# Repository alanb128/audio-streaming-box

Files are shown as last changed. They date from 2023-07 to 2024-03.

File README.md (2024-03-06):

# network-streamer
Create an audiophile streaming music device with [moOde audio](https://moodeaudio.org/), controls and an LCD

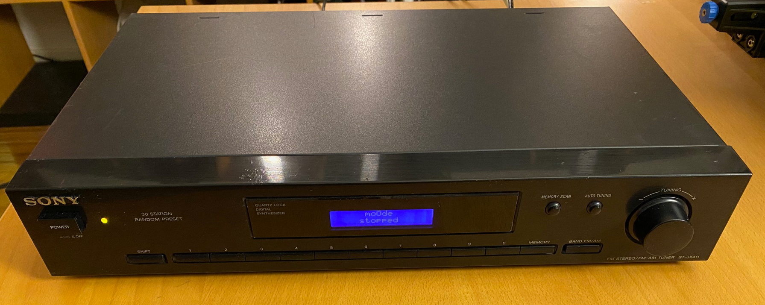
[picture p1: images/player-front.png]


## About
This project started as a means for adding a network audio streaming device to my stereo system. These devices are typically [awesome but expensive](https://www.crutchfield.com/shopsearch/network_streamer.html?&pg=2) so I decided to build one using a Raspberry Pi, an old analog AM/FM tuner's case, and the open-source moOde software. Front panel buttons can be used to select playlists, start/stop music and move to the previous and next track. When integrated into an old stereo component, it fits nicely into a stereo system. I used an old Sony ST-JX411/412/421 series of tuners from the 1990s that are a nice size and have rotary tuning knob.

See the project's video [here](https://youtu.be/9q6N7AinWJA?si=kqSZgW_-xdN4nL4z)!

I hope to add more details and instructions in the future, but the below should get ambitious makers started!

This is an advanced project that requires soldering, tinkering, and some prior experience working with the Raspberry Pi (Python and Docker experience is helpful but not required). This document outlines the basics to get started and create a minumum build. However, if you get stuck or find an issue, feel free to add an issue to this repo!

## Hardware required

- A Raspberry Pi 4-based SBC (2, 4, or 8 GB of RAM) or a CM-4
- Pi accessories such as a MicroSD card and power supply
- An audio DAC HAT for the Pi such as [this](https://www.raspberrypi.com/products/dac-pro/) or [this](https://www.raspberrypi.com/products/dac-plus/) (I used a [digital output HAT](https://www.hifiberry.com/shop/boards/hifiberry-digi2-pro/) with an outboard DAC)
- An LCD alphanumeric display like [this one](https://www.adafruit.com/product/181)
- [i2c / SPI character LCD backpack](https://www.adafruit.com/product/292) for connecting the LCD display to the Pi
- To control the device with switches, you'll need one or more momentary SPST switches, wired into a matrix (see below)

## Setup

### Hardware

- Connect the LCD display to the backpack, and the backpack to the Pi using SPI. ([instructions](https://learn.adafruit.com/i2c-spi-lcd-backpack/python-circuitpython))
- If you have the room, the backpack can be soldered right onto the LCD.
- Connect the DAC HAT to the Pi.
- Wire up your switches in a [key matrix pattern](https://pcbheaven.com/wikipages/How_Key_Matrices_Works/) (see the use of diodes in the link to improve performance)
- Wire the rows and columns of the key matrix to the Pi's GPIO pins (which may be on the DAC HAT if using one of those)
- See the [pad4pi](https://pypi.org/project/pad4pi/) library for more information about the key matrix.
- If you want a "power on" button, add a momentary pushbutton that sends GPIO 3 to ground.
  
### Software

- Download a Moode Audio image for the Pi 4, flash it to a MicroSD card and insert it into the Pi.
- Power up the Pi and make sure Moode works and you get audio out (LCD and buttons will not initially be functional)
- If using LCD, use `raspi-config` to turn on SPI for the screen.
- In the moode UI, under "Local Services" in the "System" menu, turn on "Metadata file" and "LCD updater".
- SSH into your Moode Pi (usually `ssh pi@moode.local` with password `moodeaudio`)
- Install Docker on the pi: https://raspberrytips.com/docker-on-raspberry-pi/ - make sure it starts automatically
- Clone this repo to `/usr/src/app` on device. (You can delete the "alternate" folder.)
- Adjust [the code](https://github.com/alanb128/moode-box/blob/main/controller/flask-api.py#L83) in flask-api on the device to correspond to the GPIO pins you used for your key matrix rows and columns 
- Update `/var/local/www/commandw/lcd_updater.py` and `restart.sh` with the included modified files.
- Issue `docker compose up -d` to start the container. It should always load on its own going forward.

If you make a change to any of the files on the device after this process, issue `docker compose down` then `docker compose build` then `docker compose up`.

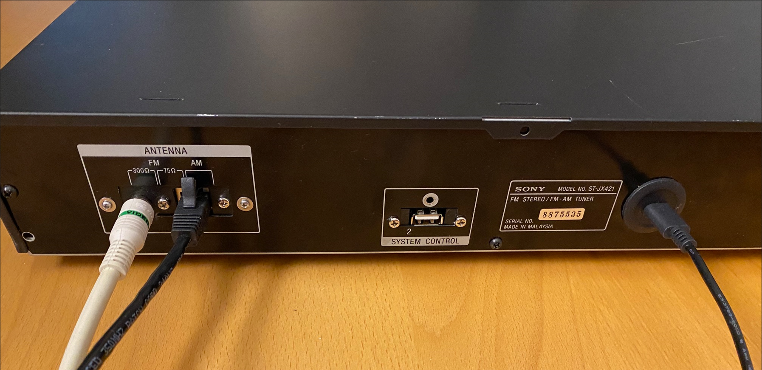
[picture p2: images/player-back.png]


## Reference files

These may be helpful for further programming in the future:

FYI: output of `cat  /var/local/www/currentsong.txt` for both playing a file then playing a stream:

```
file=NAS/Flacs/The Temptations/Vintage Gold/04 - Since I Lost My Baby.flac
artist=The Temptations
album=Vintage Gold
title=Since I Lost My Baby
coverurl=/coverart.php/NAS%2FFlacs%2FThe%20Temptations%2FVintage%20Gold%2F04%20-%20Since%20I%20Lost%20My%20Baby.flac
track=4
date=
composer=
encoded=File does not exist
bitrate=0 bps
outrate=0 bps
volume=100
mute=0
state=stop
```

```
/var/local/www/commandw/lcd_updater.py
/var/local/www/currentsong.txt
pi@moode-dev:~/moodisp $ cat  /var/local/www/currentsong.txt
file=https://ice.cr1.streamzilla.xlcdn.com:8000/sz=RCOLiveWebradio=mp3-192
artist=Radio station
album=RCO Live
title=Robert Schumann: Symphony No. 2 in C major, Op. 61 - RCO Amsterdam - John Eliot Gardiner (7.3.2010)
coverurl=imagesw%2Fradio-logos%2FRCO%20Live.jpg
track=
date=
composer=
encoded=VBR
bitrate=192 kbps
outrate=16 bit, 44.1 kHz, Stereo, 1.411 Mbps
volume=60
mute=0
state=play
```

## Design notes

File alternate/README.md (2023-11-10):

## Alternate

This was the initial setup, using four pushbuttons and an [1.27" OLED screen](https://www.adafruit.com/product/1673).

Using the [Split Body Case DIY 4.72 x 3.82 x 1.57 inch enclosure](https://www.amazon.com/gp/product/B010DHQPVW) and replacing the front and back panel with the 3d printed STL files in the "alternate" folder.

A "power on" momentary pushbutton sends GPIO 3 to ground. The display uses a [3.3v L4931 voltage regulator](https://www.adafruit.com/product/2166) and a 10uf 50v capacitor to provide additional 3v power to the LCD since the HiFiberry Digi2-Pro has 3V current restrictions.

To set this up, use raspi-config to turn on SPI for the screen. Then:

```
sudo pip3 install adafruit-circuitpython-rgb-display
sudo apt-get install fonts-dejavu
sudo apt-get install python3-pil #(Version: 8.1.2 already installed)
```

Update `/var/local/www/commandw/lcd_updater.py` with the code in this repo's alternate folder.

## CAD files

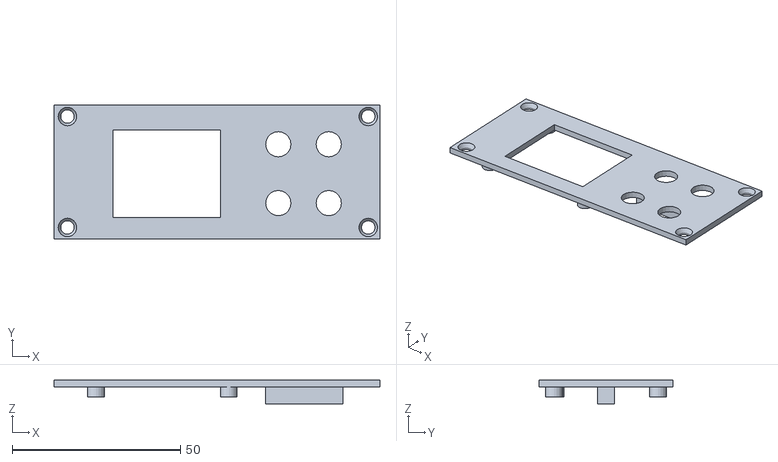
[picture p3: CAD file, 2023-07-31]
alternate/mplayer-f-2e.stl
97.0 x 40.0 x 7.00

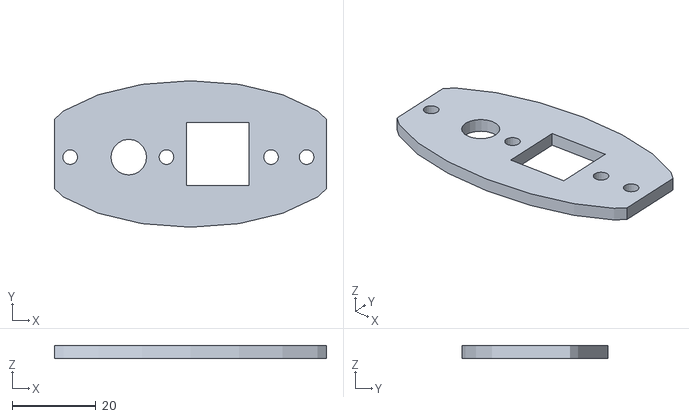
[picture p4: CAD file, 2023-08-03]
st-jx421-eth2b.stl
65.0 x 35.0 x 3.00

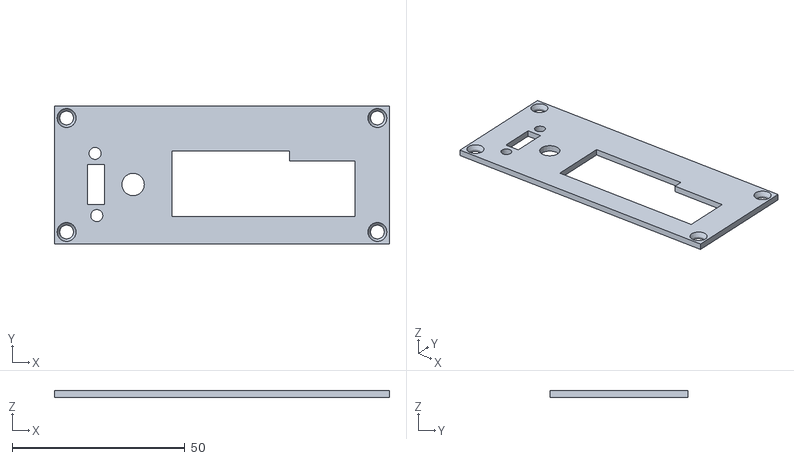
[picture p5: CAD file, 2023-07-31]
alternate/mplayer-r-2b.stl
97.0 x 40.0 x 2.00

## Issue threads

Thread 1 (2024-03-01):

Code related to two colors LED and power button.

net4u, 2024-03-01:
Hello! Can I ask you to help me extract from your source code, only what is strictly related to the power button and the two LEDs (red and green).

alanb128, 2024-03-01:
Hi @net4u - For power on, the momentary switch just needs to connect pin 3 of the PI to ground momentarily. The red and green LEDs are connected to GPIO pins (with resistors) as outputs. In the [power on sequence](https://github.com/alanb128/audio-streaming-box/blob/9c3bc8f823c2baca6be2a2adfcf1c77c53a1da1b/controller/flask-api.py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), the red LED is tuned off and the green is turned on. During [shutdown](https://github.com/alanb128/audio-streaming-box/blob/9c3bc8f823c2baca6be2a2adfcf1c77c53a1da1b/controller/flask-api.py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), the opposite occurs. Let me know if you need more details!

net4u, 2024-03-02:
Hi. I will try tomorrow and then come with feedback. I have to search for an extra LED in my "archived electronics boxes". Thnx a lot.

net4u, 2024-03-04:
Beyond "import RPI.GPIO" I also need to import the other libraries?

net4u, 2024-03-04:
Beyond import RPI.GPIO I need also to import the other libraries?

alanb128, 2024-03-06:
You only need the other libraries if you are doing more than setting the values for the GPIO pins. In other words, if you're just turning on and off the LEDs, that should be the only library you'll need. If you do require another library, an error message should alert you as to which one is missing.

Closed 2025-04-28.

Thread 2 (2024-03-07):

LCD / LCD Backpack wiring

stevemesser, 2024-03-07:
I am trying to make your project. I found a FM tuner exactly like yours.

1. Do you happen to have more detailed wiring information about
    a. LCD and Back pack
    b. How you wired up the tuning knob
    c. the breakout board
2. How did you power the existing front panel?

I am handy with electronics but not as handy as you. Any extra guidance you could provide would be appreciated.

alanb128, 2024-03-07:
> LCD and Back pack

Here's the guide I used for the LCD and backpack: https://learn.adafruit.com/i2c-spi-lcd-backpack

> How you wired up the tuning knob

On my Sony tuners, the tuning knob was included in the row and column matrix, so no additional wiring was required - check the schematic for your exact tuner model. (Even models that look the same can have different model numbers)

> the breakout board

The breakout board was just a way to connect the ribbon cable leads I soldered onto the tuning board to the male GPIO pins on the Pi. It can be done many ways. I used a board like this: https://www.adafruit.com/product/1608 along with a strip of male headers and female-to-female jumpers.

> How did you power the existing front panel

It is actually passive when just using the front panel switches, so no power is needed!

Good luck and keep us posted!

stevemesser, 2024-03-11:
Sony FM control panel button matrix

1. I have removed the current display
2. I have desoldered the chip that was under the display
3. Looking at the schematic I see the matrix you have mentioned in your video.
   What I see is it appears to me that
   Pins 15, 16, 24, 25 seem to be the vertical lines of the matrix
   Pins 30, 31, 33, 34, 35 seem to be the hortizontal lines of the matrix
   Not sure about pins 32 and 33.

I thought that if I connected my multimeter in continuity mode to pins 16 and 30 then pressing the Band button would get a beep. However, it did not.

What I am missing?

alanb128, 2024-03-12:
My schematic is for the "ST_JX412/JX521" so that's what I'm going by. Your numbering sounds correct, but pins 28, 29, and 33 are also rows. Pin 32 is ground - make sure you do not connect the board ground to ground on the Pi or it won't work. I did not try continuity testing on my board so I don't know if you should get a beep or not - I'm not sure how the diodes would affect that.

Also make sure you update the rows and columns in the code to correspond to the GPIO pins you use.

alanb128, 2024-03-13:
The "11 wires instead of 17" is just purely going off the schematic. In my build the four "key input" pins are the columns and the five active "key output" pins are the rows. (Two key output pins don't connect to any switches.)

stevemesser, 2024-03-13:
I have the same device and schematic as you do.
So I am trying to figure out which two wires I don't need

Pin 15 Key Input
Pin 16 Key Input
Pin 24 Key Input
Pin 25 Key Input

Pin 28 Key Output
Pin 29 Key Output
Pin 30 Key Output
Pin 31 Key Output
Pin 33 Key Output
Pin 34 Key Output
Pin 35 Key Output

My guess would be I don't need Pins 28 and 29.

Could you please verify that for me?

alanb128, 2024-03-14:
Correct, I don't think you need pin 28 and 29.

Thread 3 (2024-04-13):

Looking for some troubleshooting help

stevemesser, 2024-04-13:
I have the project completely built.  I tested button presses in a test script so that part is known to work.
My configuration is the same as yours.

I have verified the following
1. In Moode I have enabled LCD Updater
2. In raspi-config I have enables SPI
3. I have verified that currentsong.txt is being populated
4. . I have verified that the docker image is running via docker ps

The issue is that the LCD nor key presses are working.
Not sure what I missed. Not even the momentary push button to GPIO 3 works.

I haven't been able to figure out where the docker container would log errors.

Any thoughts for troubleshooting?

Thanks

alanb128, 2024-04-14:
Looks like the actual Python script may be commented out:
https://github.com/alanb128/audio-streaming-box/blob/e4b1963791e3b94d0bdc0316399793957368005a/controller/Dockerfile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
I must have been troubleshooting at some point and left that in. Comment out the "sleep" line and uncomment the line above, then try again.

stevemesser, 2024-04-14:
Thanks I saw that but wasn't sure. Turns out I had my latch connected to the wrong gpio pin.

alanb128, 2024-04-17:
Is your unit fully working now @stevemesser ?

stevemesser, 2024-04-17:
Sorry,  I got side tracked with a work project.  I hope to work on it again in the next day or so.

stevemesser, 2024-04-17:
The contract pot on the backpack is extremely fickle. I ordered another one

stevemesser, 2024-04-19:
@alanb128  I figured out all my LCD issues. I mentioned above I had tested keypresses. I did however without pad4pi. I figured out how to create a virtual environment in Thonny and was finally able to install pad4pi and write a test script. However, I am getting the following runtime error. Failed to add edge detection. Did I miss some configuration somewhere?

stevemesser, 2024-04-20:
Running the docker log <container id> command the logs are saying that flask import is failing with No module named flask.

Any ideas?

alanb128, 2024-04-20:
Looks like Flask was not being installed. I updated the Dockerfile, so try pulling it again and rebuilding.

stevemesser, 2024-04-20:
Closer, now import request fails.

No module named requests

alanb128, 2024-04-20:
Ok, added that in so you can try again.

(Sometimes I install these modules manually during development and forget to update the repo or push the changes!)

stevemesser, 2024-04-20:
No worries. thanks for helping.
=> ERROR [controller 3/4] RUN     pip3 install flask request adafruit-circuitpython-charlcd pad4pi adafruit-circuitpython-seesaw

.059 Collecting flask
3.245   Downloading flask-3.0.3-py3-none-any.whl (101 kB)
3.318      ━━━━━━━━━━━━━━━━━━━━━━━━━━━━━━━━━━━━━━━ 101.7/101.7 kB 1.6 MB/s eta 0:00:00
3.415 ERROR: Could not find a version that satisfies the requirement request (from versions: none)
3.417 ERROR: No matching distribution found for request
3.928
3.928 [notice] A new release of pip is available: 23.0 -> 24.0
3.928 [notice] To update, run: pip install --upgrade pip
------
failed to solve: process "/bin/sh -c pip3 install flask request adafruit-circuitpython-charlcd pad4pi adafruit-circuitpython-seesaw" did not complete successfully: exit code: 1

alanb128, 2024-04-20:
It should be `requests` in the Dockerfile, not `request` - I thought it was spelled correctly in the last update...

stevemesser, 2024-04-20:
LCD is now working and it stays in sync. I don't see any errors in docker logs.
However, every keypress results in the same response No Play list defined ...

stevemesser, 2024-04-20:
Button circut : board gpio

ROWS
PCB-35  GPIO-14
PCB-34  GPIO-15
PCB-33  GPIO-13
PCB-31  GPIO-23
PCB-30  GPIO-26

COLS
PCB-24  GPIO-16
PCB-25  GPIO-12
PCB-15  GPIO-25
PCB-16  GPIO-24

stevemesser, 2024-04-20:
I am seeing this in the log
172.18.0.1 - - [20/Apr/2024 16:34:46] "POST / HTTP/1.1" 204 -
172.18.0.1 - - [20/Apr/2024 16:35:26] "POST / HTTP/1.1" 204 -
172.18.0.1 - - [20/Apr/2024 16:38:49] "POST / HTTP/1.1" 204 -
172.18.0.1 - - [20/Apr/2024 16:39:19] "POST / HTTP/1.1" 204 -
172.18.0.1 - - [20/Apr/2024 16:42:23] "POST / HTTP/1.1" 204 -
172.18.0.1 - - [20/Apr/2024 16:46:13] "POST / HTTP/1.1" 204 -
172.18.0.1 - - [20/Apr/2024 16:50:46] "POST / HTTP/1.1" 204 -
172.18.0.1 - - [20/Apr/2024 16:56:02] "POST / HTTP/1.1" 204 -

alanb128, 2024-04-23:
How many playlists have you created in this instance of MoOde?

stevemesser, 2024-04-23:
I have several including favorites and default. None of the buttons do the right thing. Button 8 does next track. No idea which one is select

stevemesser, 2024-04-23:
That's why I ask how you wired your pcb to gpio pins

stevemesser, 2024-04-23:
Your code doe print statements on key presses but I don't know where it's printing to

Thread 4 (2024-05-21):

LCD I2C Direct Connection

bryanwallen, 2024-05-21:
Hi Alan. I am trying to build your Music-Streaming-Box and wish to connect a 16x2 LCD display with I2C interface directly to the SDA and SCL terminals on the Pi. However, having followed your instructions I am unable to get any data to the display. Am I doing something wrong?
regards

Bryan Allen

alanb128, 2024-05-22:
Hello Bryan, the code in this repo is for this specific LCD display: https://www.adafruit.com/product/181 and that uses SPI instead of I2C. So if you want to use I2C it is possible but you would have to use a different library and change the code accordingly.
What model display are you using?

bryanwallen, 2024-05-22:
Hi Alan. It’s an HD44780 compatible display.BryanOn 22 May 2024, at 03:33, Alan Boris ***@***.***> wrote:
Hello Bryan, the code in this repo is for this specific LCD display: https://www.adafruit.com/product/181 and that uses SPI instead of I2C. So if you want to use I2C it is possible but you would have to use a different library and change the code accordingly.
What model display are you using?

—Reply to this email directly, view it on GitHub, or unsubscribe.You are receiving this because you authored the thread.Message ID: ***@***.***>

alanb128, 2024-05-24:
If your display already has I2C and you want to connect using that method, then you'll need to modify the code a bit to work with the particular library for your display. Alternatively, you might be able to attach a backpack like this: https://www.adafruit.com/product/292 and connect to the Pi via SPI so the code works as written.

bryanwallen, 2024-05-24:
Okay, thanks for your help, Alan. I will have a look and, hopefully, get it working.Regards BryanOn 24 May 2024, at 04:44, Alan Boris ***@***.***> wrote:
If your display already has I2C and you want to connect using that method, then you'll need to modify the code a bit to work with the particular library for your display. Alternatively, you might be able to attach a backpack like this: https://www.adafruit.com/product/292 and connect to the Pi via SPI so the code works as written.

—Reply to this email directly, view it on GitHub, or unsubscribe.You are receiving this because you authored the thread.Message ID: ***@***.***>

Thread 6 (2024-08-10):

Getting multiple values from single key

reryro, 2024-08-10:
Hi Alan, great work on this.  But I've got a couple problems.  I'm working with the same Sony tuner you used and I've wired the switch board matrix to the same GPIO pins as you did (just not necessarily in the same sequence).  First problem: flask_api.py doesn't seem to run (I added some debug logging, but log file is created), so I don't get any response to my key presses.  I wanted to confirm the wiring before I proceed any further, so I wrote a test-keys script that mostly uses your keypad matrix handling code, and when I run it - second problem: each button gives me a different output value every time I press it.  Strangely, each button will generate 3 or 4 different values and keep repeating those same values as I repeatedly press that button -- but a different set of 3 or 4 values for each key, with some overlap.   I thought it was a bounce issue, so I added debounce, but same result.

Any idea what's happening here?  And why don't you see any bounce issues -- does pad4pi or Rpi_gpio include that?

Lastly, any thoughts on why flask_api doesn't run?  I followed all the install instructions, especially the "docker compose up -d" which you note "should always load on its own going forward".

alanb128, 2024-08-16:
Hello @reryro that is strange behavior on your key presses. Did you remove the original microprocessor and fluorescent display from your control board? Also make sure you don't connect that board to the Pi's ground pin. I did not use any debouncing because mine didn't seem to need it. I also suggest trying to get the keys working outside of Docker and moOde audio, perhaps on plain Pi OS. Hope this helps and good luck!

reryro, 2024-08-16:
Yes, I did remove both the IC and the display, and I also ran my test script outside of Docker and Moode. And no, I didn't connect the switch matrix to Pi ground or Vcc -- even though every schematic I've seen online for wiring up switch matrices show power connections, both positive and ground.

I'm going to try 10k pull-up resistors on the inputs (or is it outputs? I'll have to double check that) and see if that helps...

But I still have the issue of flask_api not running -- any ideas on what I may have missed there?  I don't have much experience with Docker, but I'm sure I followed all the steps.

alanb128, 2024-08-22:
It's a bit tough to troubleshoot the key press issues - even control boards of the same model may have subtle differences. I would say go back to basics - maybe even build a simple 2x2 or 4x4 key matrix and test the code...
For flask_api are you sure the container is running? You could check by running `docker ps` and see if the container is crashing (uptime would be short, like 30 seconds) I'll be revisiting this project again in the near future so hopefully I can simplify it a bit.

reryro, 2024-08-22:
I really appreciate you taking the time to respond, so much so that I'm not going to wear out my welcome with a continuing series of questions, so I'll just say this -- it's really been so frustrating to invest so much time in acquiring the parts, disemboweling the tuner, and then wiring it up to the Pi and spending dozens of hours trying to tweak the code to make it work, that I just can't bring myself to give up on it. I like too much the concept of re-using all those great buttons, so I'm going to see if I can cut the board traces and connect the switches directly to individual GPIO pins. I just hope I can find enough available after satisfying the DAC hat and display needs.

I look forward to your "revisit" of this project -- especially if that results in further insights into the "mysterious" matrix. There's one aspect of that that I have a hard time wrapping my head around -- the fact that it scans for a pin that's gone low, and then while it's low, it scans again for another pin's change in state, in order to identify which unique switch was closed. But these scans take a discreet amount of time to process, and all the while, debounce delay must be introduced in order to suppress any spurious signals -- but too much delay and you've lost the signals of the two pins. I'm just not sure how that timing works (and in my case, doesn't) and how to go about tweaking it without making it even worse.

Thanks again, Alan.

alanb128, 2024-08-22:
You're welcome! Before you give up and start cutting traces though, check for cold solder joints on the push buttons/diodes. Two of my tuners had that and it was very tough to track down the issues it was causing.

I might eliminate the key matrix in my next revision even though it has actually worked fine for me but I agree its operation is mysterious!

reryro, 2024-08-22:
Ah, interesting!  And a great suggestion -- if you saw it on two different chassis in a such a limited sample, that tells me that it's very likely a widespread problem.  I'll check mine today.  Thanks, and congrats on the catch. I'd never have thought of that!

reryro, 2024-09-02:
No response expected on this, just thought I'd update on the off chance anyone is following this thread (my sympathies to you).  I went thru the board, resoldering all of the switches and the diodes, though I may have missed some of those. The results were different from before, so I apparently fixed some problems, but alas, there were still problems.

So I gave up on the matrix -- I cut all the board traces around the switches and connected directly to them. Since I didn't have enough GPIO pins for all the switches plus the DAC plus the LCD, I inserted a MCP23017 I/O expander between the switches and the Pi. Then I first coded it in a simple polling algorithm -- that worked perfectly (after discovering and fixing some incomplete trace cuts). But not happy with perfection :-(  I decided I'd rather use the MCP23017's interrupts and get rid of the polling.

That has introduced its own problems -- interrupts sometimes not executing, switch bounce causing the interrupt clear to fail, lengthening bounce delay causing even more interrupts to be missed, etc. So, I guess I'm going back to polling...or maybe I'll just switch to crossword puzzles to occupy my mind...

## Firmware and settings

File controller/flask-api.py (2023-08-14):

from flask import Flask, jsonify, request
from pad4pi import rpi_gpio
import time

import board
import busio

import digitalio
import adafruit_character_lcd.character_lcd_spi as character_lcd
spi = busio.SPI(board.SCK, MOSI=board.MOSI)
latch = digitalio.DigitalInOut(board.D17)
cols = 16
rows = 2
lcd = character_lcd.Character_LCD_SPI(spi, latch, cols, rows)



#import adafruit_character_lcd.character_lcd_i2c as character_lcd

from adafruit_seesaw import seesaw, rotaryio
import RPi.GPIO as GPIO

import requests
import os
import socket

VERSION = 0.5
DISPLAY_RESUME = 2.66  # seconds

no_rotary = True

# Adafruit I2C QT Rotary Encoder
# Using the INT output on Pi GPIO 17
try:
    seesaw = seesaw.Seesaw(board.I2C(), addr=0x36)
except:
    print("No rotary encoder - skipping...")
else:
    seesaw_product = (seesaw.get_version() >> 16) & 0xFFFF
    print("Found seesaw supported product {}".format(seesaw_product))
    if seesaw_product != 4991:
        print("Wrong firmware loaded for QT encoder?  Expected 4991")
    # Set up the rotary click button, and add to interrupt
    seesaw.pin_mode(24, seesaw.INPUT_PULLUP)  # Pin on the QT
    seesaw.set_GPIO_interrupts(1 << 24, True)
    seesaw.enable_encoder_interrupt()
    no_rotary = False

rotary_pos = 0  # keeps track of wheel position

# Modify this if you have a different sized Character LCD
#lcd_columns = 16
#lcd_rows = 2

# Initialise I2C bus.
#i2c = board.I2C()  # uses board.SCL and board.SDA - used this
#i2c = board.STEMMA_I2C()  # For using the built-in STEMMA QT connector on a microcontroller
#i2c = busio.I2C(board.SCL, board.SDA)

# Initialise the lcd class
#lcd = character_lcd.Character_LCD_I2C(i2c, lcd_columns, lcd_rows)

# Custom chars
CHAR_PLAY = bytes([0x10,0x18,0x1c,0x1e,0x1c,0x18,0x10,0x0])
CHAR_PAUSE = bytes([0x0,0x1b,0x1b,0x1b,0x1b,0x1b,0x0,0x0])
CHAR_STOP = bytes([0x0,0x1f,0x1f,0x1f,0x1f,0x1f,0x0,0x0])
CHAR_BAR = bytes([0x0,0x1f,0x1f,0x1f,0x1f,0x1f,0x1f,0x1f])
lcd.create_char(0, CHAR_PLAY)
lcd.create_char(1, CHAR_PAUSE)
lcd.create_char(2, CHAR_STOP)
lcd.create_char(3, CHAR_BAR)

# to display play char: \x00

KEYPAD = [
        ["A","B","C","D"],
        ["E","F","G","H"],
        ["J","K","L","M"],
        ["N","P","Q","R"],
        ["T","U","V","W"]
]

ROW_PINS = [14,15,13,23,26] # BCM numbering
COL_PINS = [16,12,25,24] # BCM numbering

factory = rpi_gpio.KeypadFactory()

# Try factory.create_4_by_3_keypad
# and factory.create_4_by_4_keypad for reasonable defaults
keypad = factory.create_keypad(keypad=KEYPAD, row_pins=ROW_PINS, col_pins=COL_PINS)

current_song = {"artist": "", "album": "", "title": "", "encoded": "", "bitrate": "", "volume": 0, "mute": 0, "state": "", "hostname": "hostname", "ip": "ip", "moode": "moode"}
display_mode = 0
playlists = []
preset_keys = ["T", "N", "J", "E", "A", "U", "P", "K", "F", "B"]
current_playlist = ""  # current or most recently played playlist
sel_playlist = ""   # selected playlist before being played
last_key = ""  # help with double key press issue
last_key_count = 0  # also help with double key
current_volume = 0
line_1_mode = "title"
line_2_mode = "normal"

def lcd_display(trigger):
    #
    # Decides what should be shown on the LCD display
    #
    
    my_display = "     moOde\n     audio"  # default if no trigger
    #print("trig: {0}, l1m: {1}, l2m: {2}".format(trigger, line_1_mode, line_2_mode))
    lcd.clear()
    if trigger == "resume":
        get_current_state()
        
    if trigger == "post" or trigger == "resume":
        if current_song["state"] == "stop":
            my_display = "     moOde\n    stopped"
        else:   # pause or play
            if line_1_mode == "title":
                my_display = current_song["title"]
            elif line_1_mode == "artist":
                my_display = current_song["artist"]
            elif line_1_mode == "album":
                my_display = current_song["album"]
            
            if current_song["state"] == "pause":
                my_display = my_display + "\n\x01    paused"
            elif current_song["state"] == "play":
                my_display = my_display +  "\n\x00 " + current_song["encoded"]
            
    elif trigger == "init":
        my_display = "     moOde\n     audio"

    elif trigger == "shutdown":
        my_display = "     moOde\n   power off"

    elif trigger == "reboot":
        my_display = "     moOde\n    restarting"
        
    elif (trigger == "info"):
        if line_2_mode == "info1":
            my_display = current_song["hostname"] + "\n" + current_song["ip"]
        elif line_2_mode == "info2":
            my_display = "moOde version:\n" + current_song["moode"]

    lcd.message = my_display
    
def sanitizer(mystring):
    #
    # removes anything but letters and numbers from input string
    # strings from moode can contain all kinds of garbage
    #
    out_string = ''
    for i in mystring:
        s = ord(i)
        if (s > 31) and (s < 127):
            out_string = out_string + i

    return out_string

def get_current_state():
    #
    # get current state from moode api
    #
    global current_song, current_volume
    
    r = requests.get('http://host.docker.internal/command/?cmd=get_currentsong')
    current = r.json()
    current_song["artist"] = sanitizer(current["artist"])
    current_song["album"] = sanitizer(current["album"])
    current_song["title"] = sanitizer(current["title"])
    current_song["encoded"] = sanitizer(current["encoded"])
    current_song["bitrate"] = sanitizer(current["bitrate"])
    current_song["volume"] = sanitizer(current["volume"])
    current_song["mute"] = sanitizer(current["mute"])
    current_song["state"] = sanitizer(current["state"])
    # below not exposed by moode api
    #current_song["hostname"] = current["h_name"]
    #current_song["moode"] = current["moode_ver"]
    #current_song["ip"] = current["ip"]

    current_volume = int(current_song["volume"])
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

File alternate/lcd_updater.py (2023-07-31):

#!/usr/bin/python3
#
# moOde audio player (C) 2014 Tim Curtis
# http://moodeaudio.org
#
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

# Stub script for lcd-updater.sh daemon

#with open("/var/local/www/currentsong.txt") as file1:
#    with open("/home/pi/lcd.txt", "w") as file2:
#        for line in file1:
#            file2.write(line)

# SPDX-FileCopyrightText: 2021 ladyada for Adafruit Industries
# SPDX-License-Identifier: MIT

"""
Be sure to check the learn guides for more usage information.

This example is for use on (Linux) computers that are using CPython with
Adafruit Blinka to support CircuitPython libraries. CircuitPython does
not support PIL/pillow (python imaging library)!

Author(s): Melissa LeBlanc-Williams for Adafruit Industries
"""

import digitalio
import board
from PIL import Image, ImageDraw, ImageFont
from adafruit_rgb_display import ili9341
from adafruit_rgb_display import st7789  # pylint: disable=unused-import
from adafruit_rgb_display import hx8357  # pylint: disable=unused-import
from adafruit_rgb_display import st7735  # pylint: disable=unused-import
from adafruit_rgb_display import ssd1351  # pylint: disable=unused-import
from adafruit_rgb_display import ssd1331  # pylint: disable=unused-import

def left(s, amount):
    return s[:amount]

def right(s, amount):
    return s[-amount:]

def mid(s, offset, amount):
    return s[offset:offset+amount]

# Configuration for CS and DC pins (these are PiTFT defaults):
cs_pin = digitalio.DigitalInOut(board.CE0)
dc_pin = digitalio.DigitalInOut(board.D25)
reset_pin = digitalio.DigitalInOut(board.D24)

# Config for display baudrate (default max is 24mhz):
BAUDRATE = 24000000

# Setup SPI bus using hardware SPI:
spi = board.SPI()
# pylint: disable=line-too-long
# Create the display:
# disp = st7789.ST7789(spi, rotation=90,                            # 2.0" ST7789
# disp = st7789.ST7789(spi, height=240, y_offset=80, rotation=180,  # 1.3", 1.54" ST7789
# disp = st7789.ST7789(spi, rotation=90, width=135, height=240, x_offset=53, y_offset=40, # 1.14" ST7789
# disp = st7789.ST7789(spi, rotation=90, width=172, height=320, x_offset=34, # 1.47" ST7789
# disp = st7789.ST7789(spi, rotation=270, width=170, height=320, x_offset=35, # 1.9" ST7789
# disp = hx8357.HX8357(spi, rotation=180,                           # 3.5" HX8357
# disp = st7735.ST7735R(spi, rotation=90,                           # 1.8" ST7735R
# disp = st7735.ST7735R(spi, rotation=270, height=128, x_offset=2, y_offset=3,   # 1.44" ST7735R
# disp = st7735.ST7735R(spi, rotation=90, bgr=True,                 # 0.96" MiniTFT ST7735R
# disp = ssd1351.SSD1351(spi, rotation=180,                         # 1.5" SSD1351
disp = ssd1351.SSD1351(spi, height=96, width=128, y_offset=32, #rotation=180, # 1.27" SSD1351
# disp = ssd1331.SSD1331(spi, rotation=180,                         # 0.96" SSD1331
#disp = ili9341.ILI9341(
#    spi,
#    rotation=90,  # 2.2", 2.4", 2.8", 3.2" ILI9341
    cs=cs_pin,
    dc=dc_pin,
    rst=reset_pin,
    baudrate=BAUDRATE,
)
# pylint: enable=line-too-long


# Create blank image for drawing.
# Make sure to create image with mode 'RGB' for full color.
if disp.rotation % 180 == 90:
    height = disp.width  # we swap height/width to rotate it to landscape!
    width = disp.height
else:
    width = disp.width  # we swap height/width to rotate it to landscape!
    height = disp.height
image = Image.new("RGB", (width, height))

# Get drawing object to draw on image.
draw = ImageDraw.Draw(image)

# Draw a black filled box as the background
draw.rectangle((0, 0, width, height), fill=(0, 0, 0))
disp.image(image)

# Draw sections
draw.rectangle(
    (0, 0, width, 20), fill=(96, 96, 96)
)

draw.rectangle(
    (0, 77, width, height), fill=(96, 96, 96)
)


# Load a TTF Font
font = ImageFont.truetype("/usr/share/fonts/truetype/dejavu/DejaVuSans.ttf", 14)
font2 = ImageFont.truetype("/usr/share/fonts/truetype/dejavu/DejaVuSans.ttf", 18)

d_artist = ""
d_title = ""
d_encode = ""
d_state = ""
d_time = ""
d_bitrate = ""
d_album = ""

# Get text
with open("/var/local/www/currentsong.txt") as file1:
    for line in file1:
        if left(line, 7) == "artist=":
            d_artist = line[7:]
        if left(line, 6) == "title=":
            d_title = line[6:]
        if left(line, 8) == "encoded=":
            d_encode = line[8:]
        if left(line, 8) == "bitrate=":
            d_bitrate = line[8:]
        if left(line, 6) == "state=":
            d_state = line[6:]
        if left(line, 6) == "album=":
            d_album = line[6:]

d_encode = d_encode[:-1]  # appears to have a newline at end, cutting it out
d_stream = "{0}, {1}".format(d_encode, d_bitrate)
d_state = d_state[:-1]  # appears to have a newline at end, cutting it out
d_artist = d_artist[:-1]

if d_artist == "Radio station":
    d_artist = d_album

# draw play or stop shape

if d_state == "stop":
    #print("draw stop")
    draw.rectangle(
    (2, 4, 12, 14), fill=(255, 128, 0)
)

if d_state == "pause":
    draw.rectangle(
    (2, 4, 6, 14), fill=(255, 128, 0)
)
    draw.rectangle(
    (8, 4, 12, 14), fill=(255, 128, 0)
)

if d_state == "play":
    draw.polygon([(2,4), (12,9), (2,14)], fill = (255,128,0))
# Draw Some Text

draw.text(
    (20, 2),
    d_stream,
    font=font,
    fill=(192, 192, 192),
)

draw.text(
    (2,25),
    d_title,
    font=font2,
    fill=(255, 128, 0),
)

draw.text(
    (2,50),
    d_artist,
    font=font2,
    fill=(224, 224, 224),
)

# Display image.
disp.image(image)

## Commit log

2023-06-15 added two display buttons
2023-06-20 Bug fixes, more buttons
    [flask-api.py]
2023-08-02 Change to SPI, more features
    Added SPI, shutdown, reboot, more buttons, etc...
    [flask-api.py]
2023-08-14 Add pwr LED code

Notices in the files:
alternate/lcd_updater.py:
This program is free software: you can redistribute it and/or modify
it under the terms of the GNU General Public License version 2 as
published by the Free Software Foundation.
